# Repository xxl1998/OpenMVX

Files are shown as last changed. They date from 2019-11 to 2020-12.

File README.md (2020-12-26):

# OpenMVX
**a customized openmv camera,based on the openmv camera.**
**now only STM32H743+OV7725 FPC version (openMV4)**

## license

**OpenMVX is licensed under the GNU General Public Licence (GPL)V3.0**

**注意，此repository下开源的所有文件使用GPL V3.0协议，如果你用了这里的文件，那么你也要开源你的设计（也必须使用GPL协议）**

个人定制版openmv，使用官方原版openmv4硬件文件修改而来，三次打样（修改两次）后实现全部功能，使用国内常用元件，保证都是淘宝容易买到的，并且简化一部分电路设计，去掉BTB接口，直接单板实现，使用FPC镜头，焊接个FPC座就行，免得焊BGA的感光元件，现在只有STM32H743VIT6+OV7725（FPC小镜头），一体化设计，兼容原版尺寸接口，去掉不必要的SWD接口，OV7725独立供电，大部分功能已验证过（包括摄像头、TF卡、串口、SPI屏幕、当然肯定有USB连接上位机），在电赛时也使用过，好几个月了没出过问题。

没有key，即“盗版 openmv”，除每次弹窗外不影响使用，固件使用DFU刷入，SWD是没有用的，所以去掉了。
给出原理图、PCB、PCB工程文件、集成封装库等硬件全部文件，Altium Designer 16格式（AD16）。
（使用原版openmv二次修改而来，已包含原版openmv的license文件：master/openmv LICENSE.txt）

## 怎么烧固件：

我已经录制了烧录固件教程，每一步都有说明，视频链接：

https://www.bilibili.com/video/BV1Gy4y1q7NB/

4K分辨率，有字幕有链接

## 高频问题解答：  

### 为什么MCU两颗LDO供电？

**习惯而已，一颗也行，OV7725也可以公用，整个PCB就一个3.3V的LDO也行，只要电流够用。**    

### 是几层板？

**两层板常规工艺，走到哪都不用加钱的那种。**（客编我都给你放好了，下单掏5块钱就行）

### DFU烧录固件卡在66%？

**这不是个例，我用的是硬件版本Y的芯片烧录固件完全正常，硬件版本V的芯片出现此问题，原因尚不清楚。目前（2019年底以后）市面上基本没有Y版本的芯片了，解决办法由群友提供，群友在2020-3-18上传的PDF有详细教程，好几个群友已经DIY成功。**

烧录固件视频教程近期将更新，敬请期待

### 引出排针有个空脚？

**那是外部帧同步信号，BGA的OV7725有，FPC的OV7725没有这个引脚，为了与OpenMV官方版引脚兼容，此引脚悬空。**

### 元件在哪买？ 

**已更新了带淘宝链接的BOM，仅供参考，购买后果自行承担。摄像头搜索关键词“OV7725 FPC”，我用的是长度21mm的**

### 关于FPC座子的封装？ 

**我使用24pin FPC座的封装1号脚在右侧，而OV7725的1号脚在左侧，所以在Pin map里将引脚映射反向，这样引脚顺序就对了。（前提是FPC座是翻盖下接），直接打板是肯定没问题的。**

**详细讲解请看：关于pin map.md**

## 预览PCB

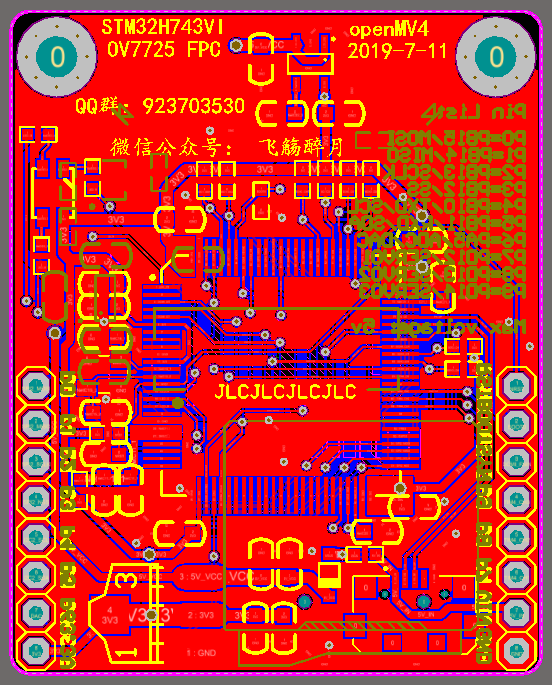
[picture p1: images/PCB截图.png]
Image_text

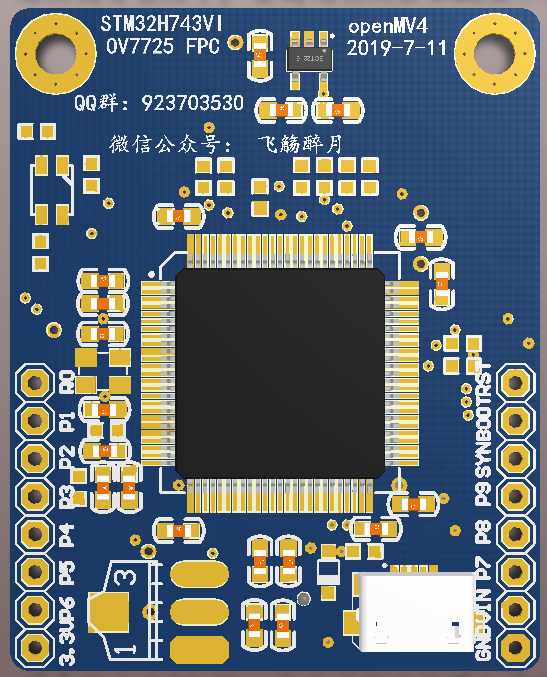
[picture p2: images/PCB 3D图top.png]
Image_text

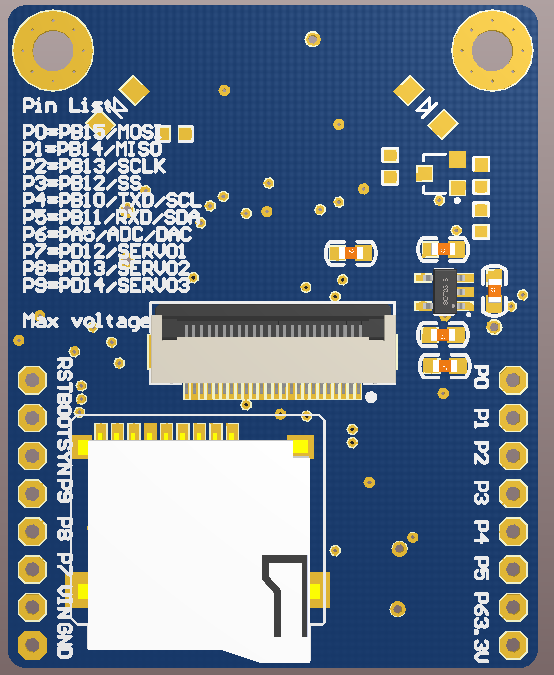
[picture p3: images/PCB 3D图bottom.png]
Image_text


## 实拍效果

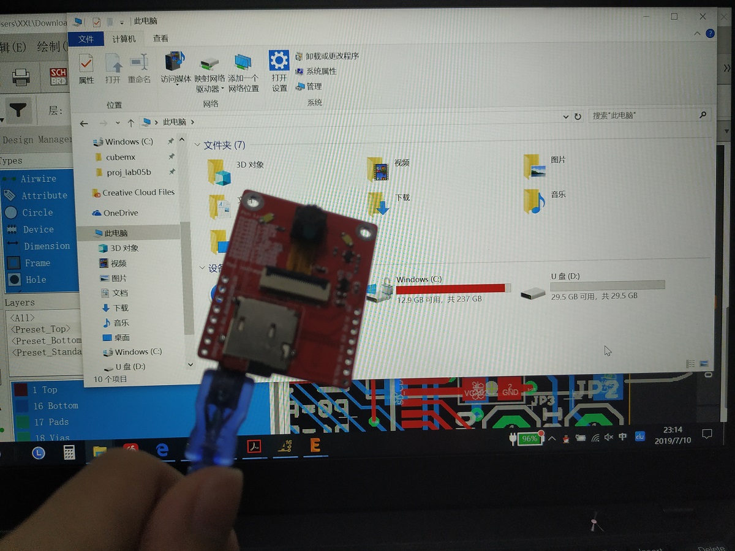
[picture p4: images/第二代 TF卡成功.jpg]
Image_text

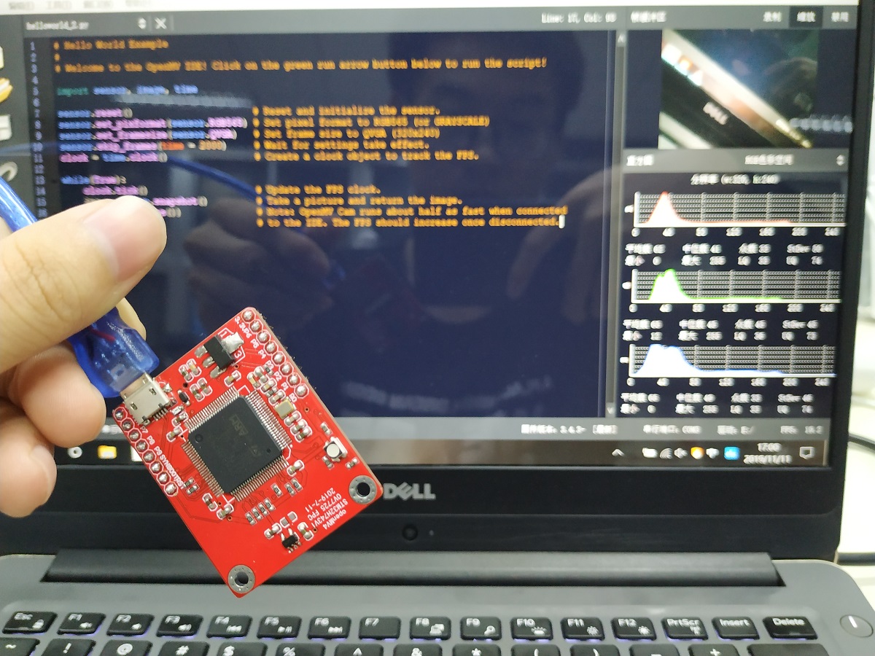
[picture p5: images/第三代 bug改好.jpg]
Image_text


## about

**有任何技术问题，可加QQ群 923703530**

**更多技术分享和作品开源分享，可关注微信公众号： 飞觞醉月**    

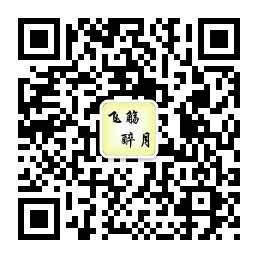
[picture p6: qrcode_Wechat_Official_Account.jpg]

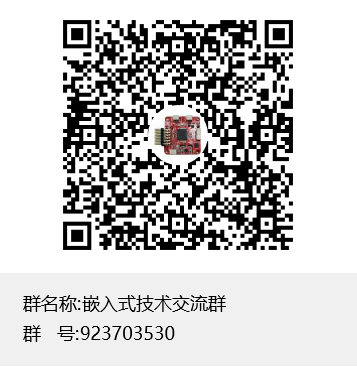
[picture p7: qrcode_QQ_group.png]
Image text


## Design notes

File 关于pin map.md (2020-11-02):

# 关于pin remap

## 起因

下面是两个从淘宝OV7725详情页拿到的引脚定义，请观察**OV7725的1号脚在哪边？**

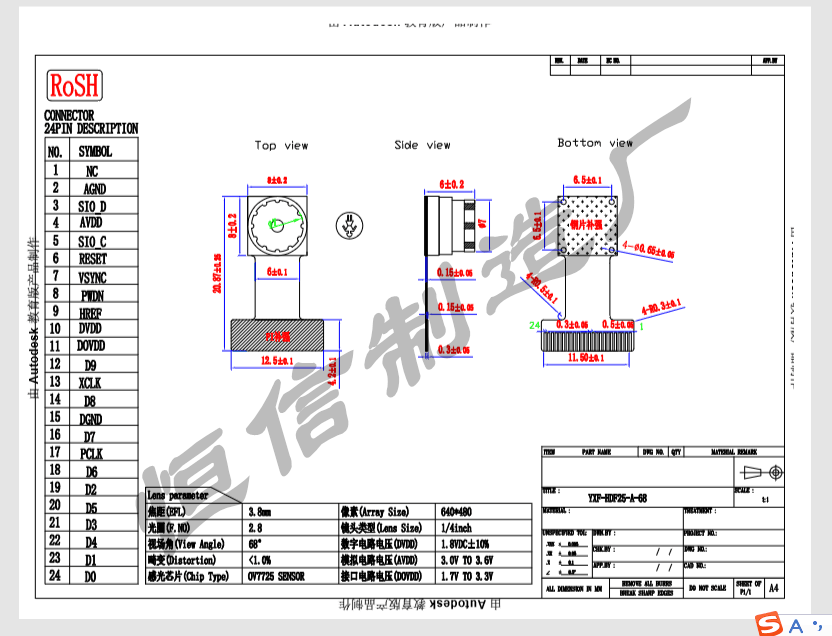
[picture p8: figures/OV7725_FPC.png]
OV7725-FPC


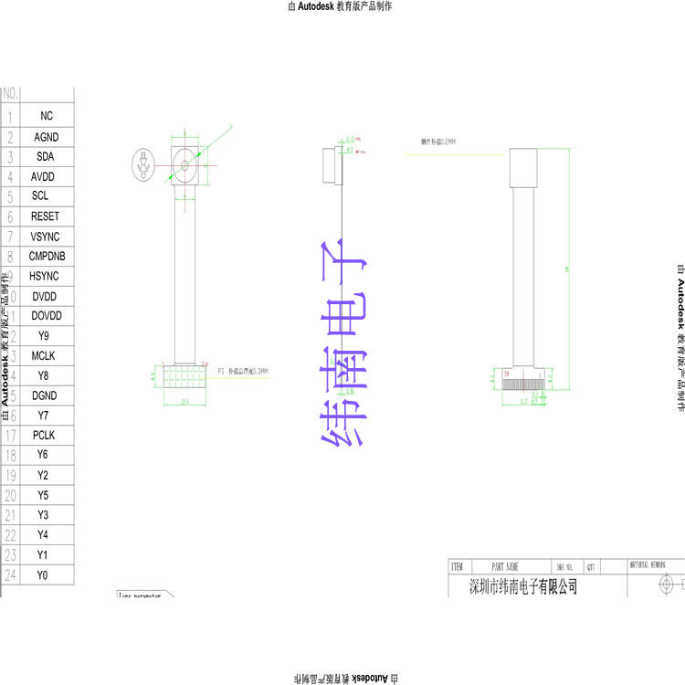
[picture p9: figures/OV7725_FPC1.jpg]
OV7725-FPC1


在两个图片中，都有正视（摄像头向上，图左）、侧视（图中）、后视（图右）

标有引脚序号的都是后视图，并且在后视图中1号脚在右边

所以，OV7725在**正视图中，1号脚在左边**

下面再看我的FPC座子封装：

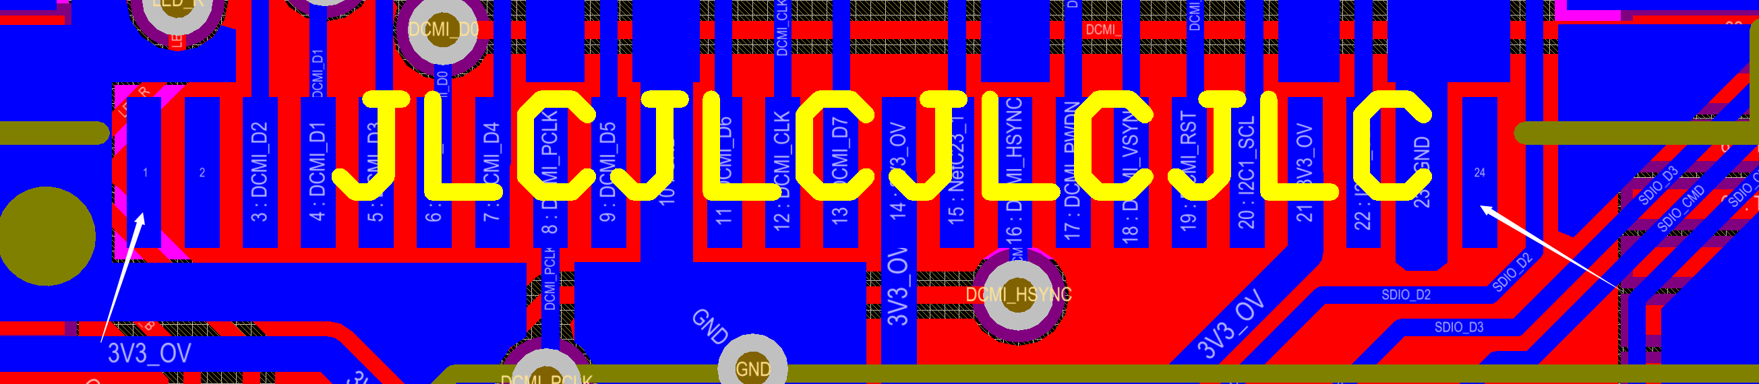
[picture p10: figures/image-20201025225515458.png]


请注意观察白色箭头处

在bottom layer，1号脚在左边，所以当正视时，FPC座子的1号脚在右边

刚好和OV7725的**引脚顺序相反**

（注意这里是顺序相反，而不是仅有1和24反了，真的有人认为只有1和24）

## 解决办法

因为现有的封装的1号脚和OV7725图里的是反的（这代表从1到24都是反的，而不是只有1和24！！！！！！！！！！）所以我们要将所有引脚反向连接（而不是交换1和24），或者手动画一个新的FPC封装！

我选择了**引脚反向连接**

也就是在pin map里面修改

(pin map编辑：双击原理图中的OV7725，选择PCB封装，点击edit，弹出的窗口中右上角有pinmap按钮)

双击原理图中的OV7725，点击edit pins，出现这个窗口：

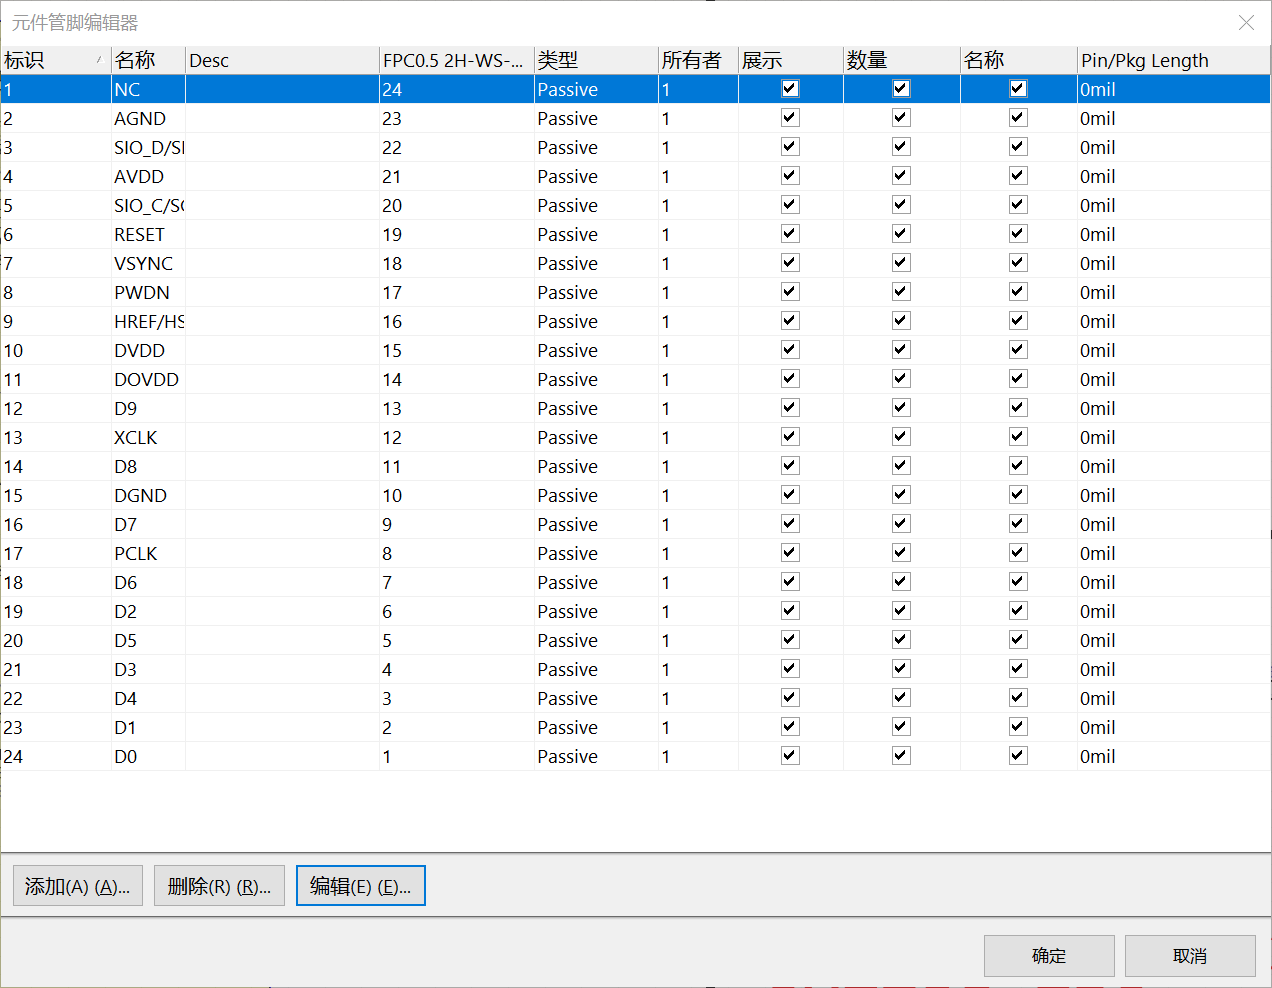
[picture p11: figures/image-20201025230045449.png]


你可以发现，我把1到24反过来对应了（**注意第一列和第四列**），也就是前面说的反向连接，解决了FPC封装1号引脚和OV7725不一样的问题，但也让我多花了n个小时用于向n个人解释n遍（所以又更新了这个文章）

## 验证结果

下面来验证这一做法是否有效，

下面两个图分别是我画的原理图库和OV7725规格书中的引脚定义，

请观察**二者是否一致（序号以及对应的名字）**

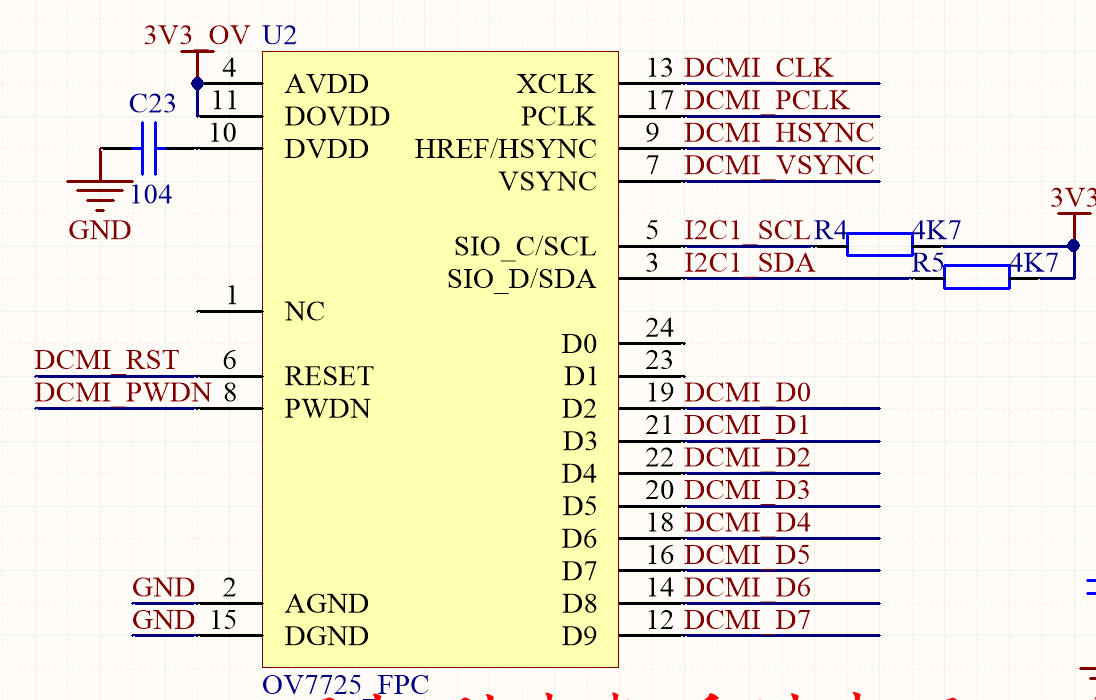
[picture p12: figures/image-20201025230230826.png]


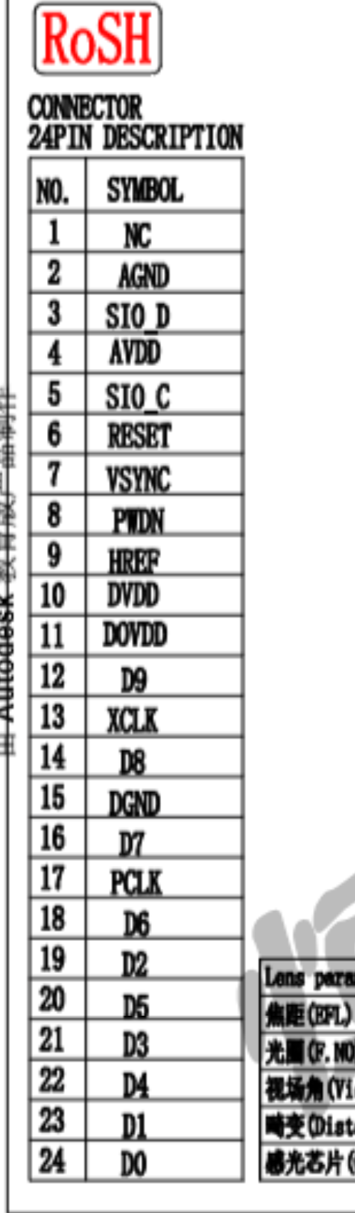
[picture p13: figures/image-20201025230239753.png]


原理图检查无误，下面检查PCB，

由于**DCMI的连接是忽略低位信号线**，所以我们只判断顺序是否反了，不判断具体接线（PCB中只显示焊盘连接的net名字而不显示它的原理图的引脚的名字，比如原理图封装的AVDD实际在PCB中显示它连接的3V3_OV这个net）

二者都选择背面的视图

从背面看：OV7725左边24脚，应该是放了一堆数据线，在原理图中我们悬空了两个，剩下的数据线都连了，OV7725右边1号脚悬空，2号脚GND，3号脚名字SIO_D连接的是SDA

从背面看：

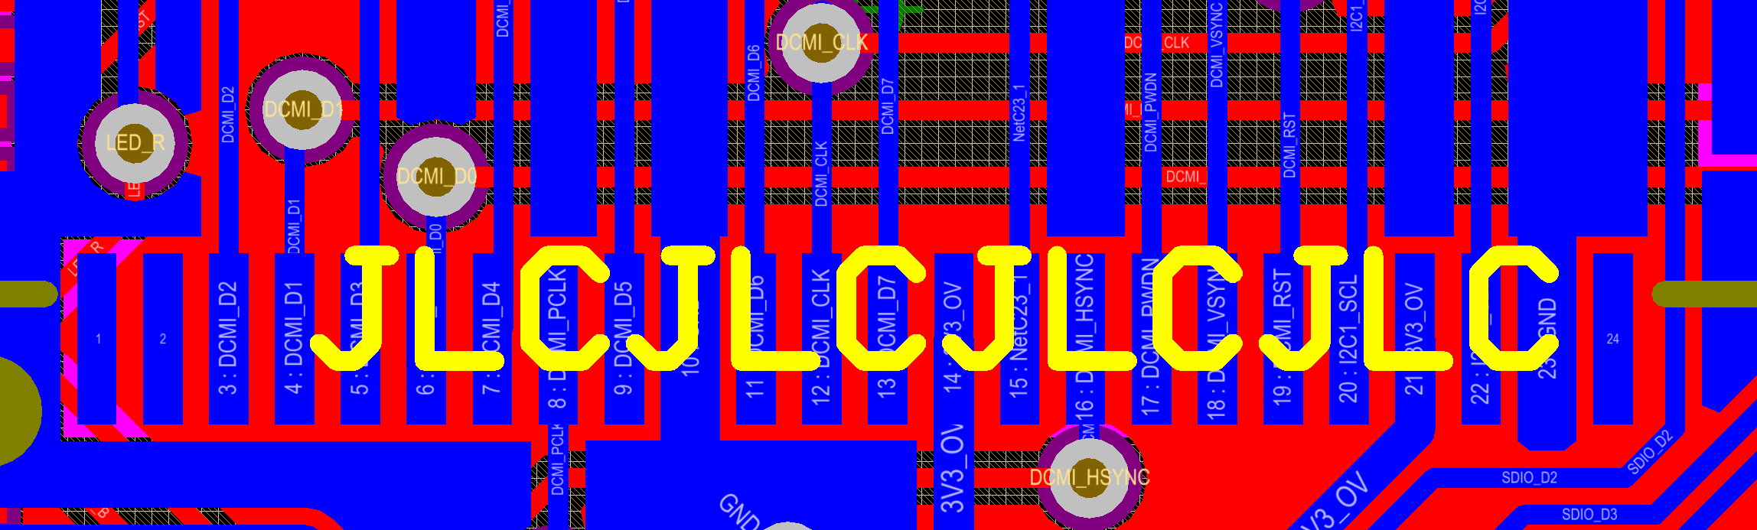
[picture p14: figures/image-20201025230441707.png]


FPC左边1,2脚，悬空了，然后是一堆数据线，FPC右边1个悬空，1个GND，1个SDA

对比PCB和OV7725的规格书，二者1号脚位置不同，但接线却是对的，验证了pin map的有效性

同时我们也可以总结出，AD的pin map只改变net的连接，而不改变你在PCB中看到的引脚序号

最后还是那句话：不动手只看教程是学不会的

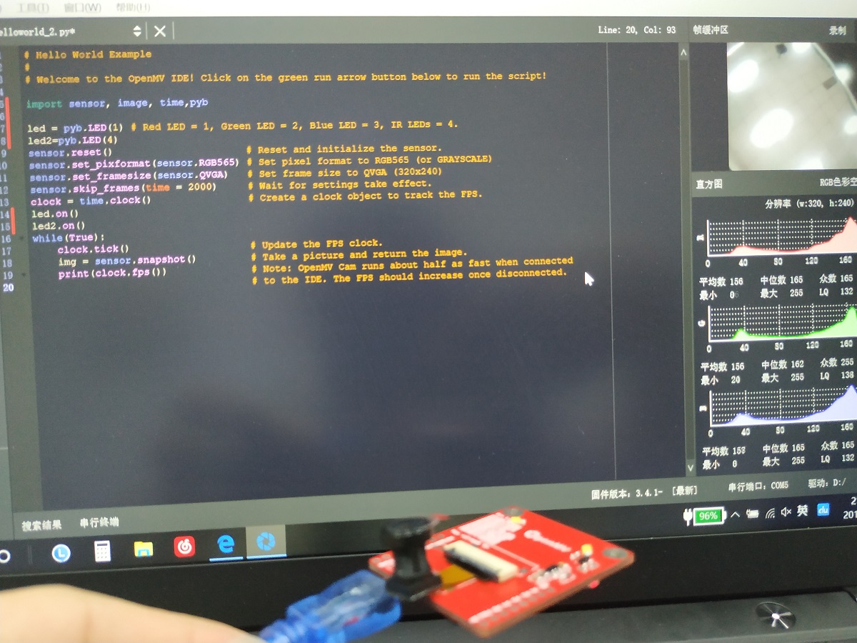
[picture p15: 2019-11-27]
images/第一代 广角镜头.jpg

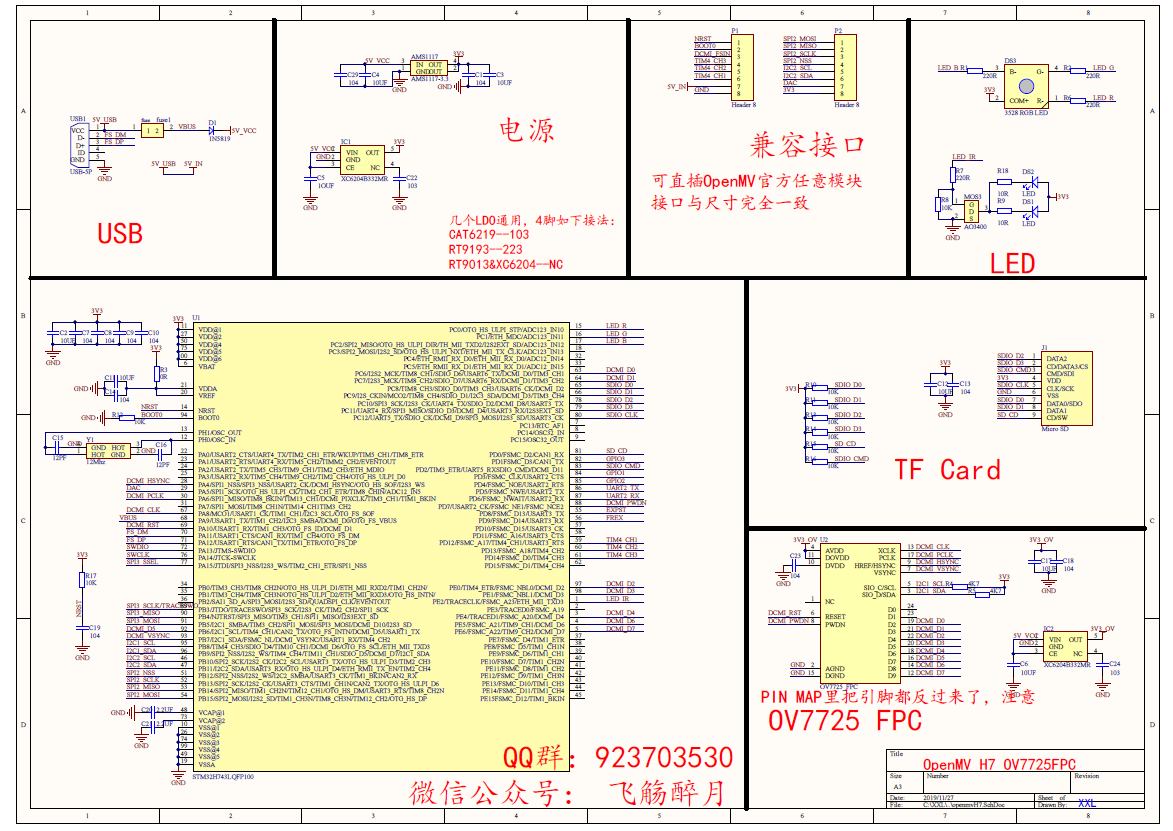
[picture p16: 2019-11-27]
images/原理图截图.png

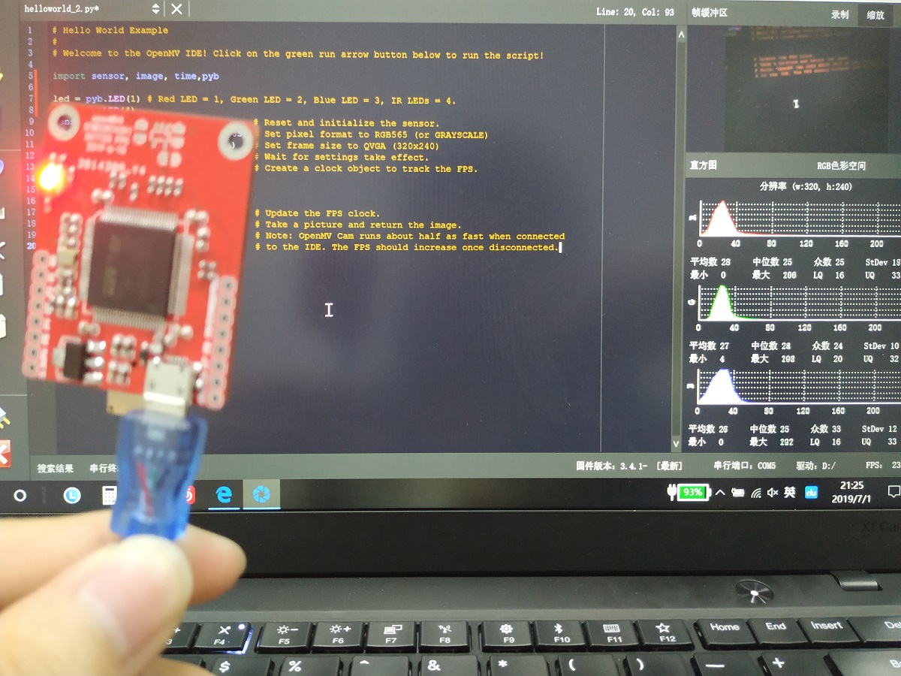
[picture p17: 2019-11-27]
images/第一代 普通镜头.jpg

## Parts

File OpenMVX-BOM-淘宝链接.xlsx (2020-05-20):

Comment | Description | Designator | Footprint | LibRef | Quantity | 淘宝链接
AMS1117-3.3 |  | AMS1117 | AMS1117 | AMS1117 | 1 | https://item.taobao.com/item.htm?spm=a1z09.2.0.0.e1252e8diDGTqS&id=522572478170&_u=k2oufh50cb68
104 |  | C1, C7, C8, C9, C10, C13, C14, C18, C19, C23, C29 | C_0603 | C_0603 | 11 | https://item.taobao.com/item.htm?spm=a1z10.3-c-s.w4002-21223910208.56.19536a4bEyIiqU&id=560792484597
10UF |  | C2, C3, C4, C6, C11, C12, C17 | C_0603 | C_0603 | 7 | https://item.taobao.com/item.htm?spm=a1z10.3-c-s.w4002-21223910208.31.594e6a4bBIApfw&id=537669338432
1OUF |  | C5 | C_0603 | C_0603 | 1 | https://item.taobao.com/item.htm?spm=a1z10.3-c-s.w4002-21223910208.31.594e6a4bBIApfw&id=537669338432
12PF |  | C15, C16 | C_0603 | C_0603 | 2 | https://item.taobao.com/item.htm?spm=a1z10.3-c-s.w4002-21223910208.10.1cc56a4bILTBmO&id=560923686976
2.2UF |  | C20, C21 | C_0603 | C_0603 | 2 | https://item.taobao.com/item.htm?spm=a1z10.3-c-s.w4002-21223910208.10.334e6a4brcYKyh&id=537748332746
103 |  | C22, C24 | C_0603 | C_0603 | 2 | https://item.taobao.com/item.htm?spm=a1z10.3-c-s.w4002-21223910208.64.ee166a4bYFIXQ6&id=537741832875
1N5819 |  | D1 | SOD-323 | D | 1 | https://item.taobao.com/item.htm?spm=a1z10.3-c-s.w4002-21223910208.9.28f66a4bAw4MZU&id=522574162326
LED |  | DS1, DS2 | LED-1206 | LED | 2 | https://item.taobao.com/item.htm?spm=a1z09.2.0.0.e1252e8diDGTqS&id=522573297043&_u=k2oufh502a5f
3528 RGB LED |  | DS3 | 3528/1210RGB LED | 3528RGB LED | 1 | https://item.taobao.com/item.htm?spm=a1z09.2.0.0.e1252e8diDGTqS&id=544589431307&_u=k2oufh509c0f
fuse0603 |  | fuse1 | 0603P | FUSE | 1 | https://item.taobao.com/item.htm?spm=a1z09.2.0.0.e1252e8diDGTqS&id=560313507871&_u=k2oufh50519e
XC6204B332MR | LDO | IC1, IC2 | SOT23-5L | LDO XC6204 | 2 | https://detail.tmall.com/item.htm?id=561325190638&spm=a1z09.2.0.0.e1252e8diDGTqS&_u=k2oufh500c87
Micro SD | Micro SD卡 | J1 | Micro SD | Micro SD | 1 | https://item.taobao.com/item.htm?spm=a1z09.2.0.0.e1252e8diDGTqS&id=522573245737&_u=k2oufh50eb54
AO3400 | AO3400A | MOS3 | SOT-23 | MOS-N | 1 | https://item.taobao.com/item.htm?spm=a1z09.2.0.0.e1252e8diDGTqS&id=522574089119&_u=k2oufh506b0d
Header 8 | Header, 8-Pin | P1, P2 | 1X08 | Header 8 | 2 | https://item.taobao.com/item.htm?spm=a1z10.3-c-s.w4002-21223910208.19.68076a4bUvQEPA&id=553875848479
220R |  | R1, R2, R6, R7 | 0603P | R | 4 | https://item.taobao.com/item.htm?spm=a1z10.3-c-s.w4002-21223910208.19.183a6a4bxAyRwa&id=525699271900
0R |  | R3 | 0603P | R | 1 | https://item.taobao.com/item.htm?spm=a1z10.3-c-s.w4002-21223910208.9.c5ec6a4b7AkZpH&id=584519288165
4K7 |  | R4, R5 | 0603P | R | 2 | https://item.taobao.com/item.htm?spm=a1z10.3-c-s.w4002-21223910208.20.5a916a4bpnsYCB&id=525820369368
10K |  | R8, R10, R11, R12, R13, R14, R15, R16, R17 | 0603P | R | 9 | https://item.taobao.com/item.htm?spm=a1z10.3-c-s.w4002-21223910208.11.5a916a4bpnsYCB&id=525777943950
10R |  | R9, R18 | 0603P | R | 2 | https://item.taobao.com/item.htm?spm=a1z10.3-c-s.w4002-21223910208.41.5a916a4bpnsYCB&id=525724626983
STM32H743LQFP100 |  | U1 | LQFP-100PIN | STM32H743LQFP100 | 1 | https://item.taobao.com/item.htm?spm=a1z09.2.0.0.e1252e8diDGTqS&id=576900393210&_u=k2oufh508064
OV7725_FPC |  | U2 | FPC0.5 2H-WS-24P | OV7725 FPC 24P 0.5MM | 1 | https://item.taobao.com/item.htm?spm=a1z09.2.0.0.e1252e8diDGTqS&id=552629356951&_u=k2oufh503808 | 24P 翻盖下接
USB-5P | 微型USB母座 | USB1 | MICRO_USB | USB-5P | 1 | https://item.taobao.com/item.htm?spm=a1z09.2.0.0.e1252e8diDGTqS&id=538147861054&_u=k2oufh50bc17
12Mhz | 3225贴片无源晶振 | Y1 | XTAL3225 | XTAL_3225 | 1 | https://item.taobao.com/item.htm?spm=a1z09.2.0.0.e1252e8diDGTqS&id=522572354913&_u=k2oufh50ec0b
以上链接仅供参考，具体购买与否请自行决定。因元件错误或质量问题带来的PCB无法正常工作或器件烧毁等一切后果由下单者与焊接者承担，与本人无关。

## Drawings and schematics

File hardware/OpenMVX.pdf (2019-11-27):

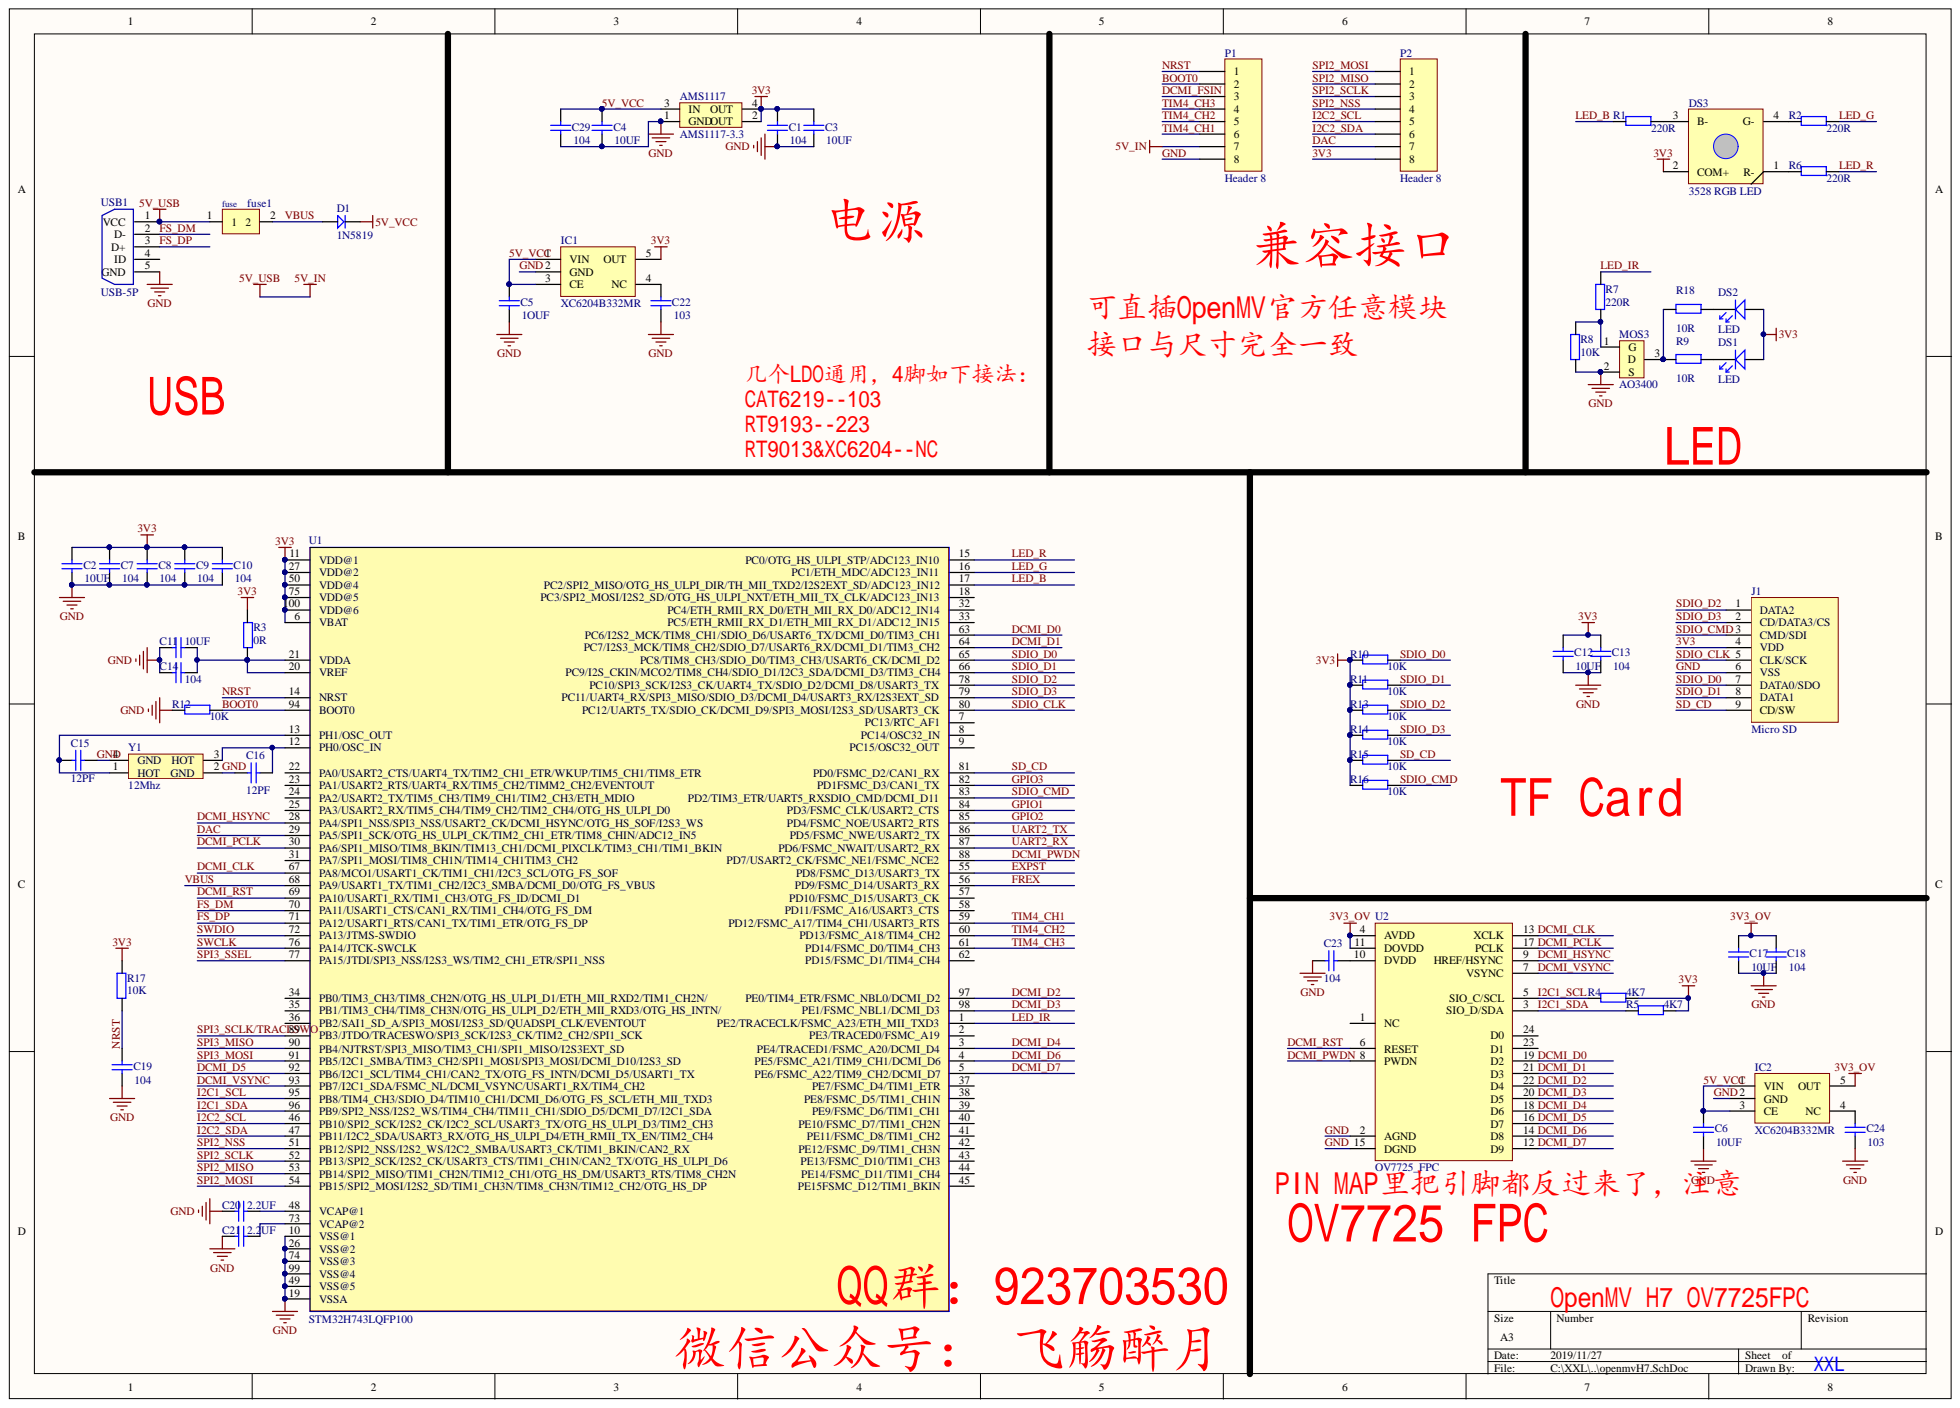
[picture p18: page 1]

GND

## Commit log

2019-11-25 add QRcodes
    QQ群和微信公众号的二维码
2019-11-25 openmv license
    因为使用了openmv原版文件重新设计，所以加入openmv的license文件
2019-11-27 all hardware files
    上传自制openmv的所有硬件文件，最新版，bug都已改掉，可直接打样，已导出原理图PDF方便阅读，已生成集成库方便画板
    [OpenMVX.PrjPcb, OpenMVX.SchDoc]
2019-11-27 一些重要图片，可预览效果
2020-05-20 更新BOM-淘宝链接
    仅供不知道器件是啥的小白参考，买错后果自行承担。
    [OpenMVX-BOM-淘宝链接.xlsx]
2020-05-24 更新二维码
    更新QQ群二维码，群聊名称已修改
